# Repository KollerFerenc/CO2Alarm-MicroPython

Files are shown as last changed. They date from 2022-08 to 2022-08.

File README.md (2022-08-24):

# Carbon dioxide (CO<sub>2</sub>) alarm

## Table of Contents

- [Carbon dioxide (CO<sub>2</sub>) alarm](#carbon-dioxide-cosub2sub-alarm)
  - [Table of Contents](#table-of-contents)
  - [Hardware Requirements](#hardware-requirements)
  - [Assembly and wiring](#assembly-and-wiring)
    - [LiPo SHIM for Pico](#lipo-shim-for-pico)
    - [Buzzer](#buzzer)
    - [SCD41 CO2 Sensor](#scd41-co2-sensor)
    - [Diagram](#diagram)
  - [Software and installation](#software-and-installation)
    - [Prerequisites](#prerequisites)
    - [Instalation](#instalation)

## Hardware Requirements

- 1x [Raspberry Pi Pico](https://www.raspberrypi.com/products/raspberry-pi-pico/)
- 1x [SCD41 CO2 Sensor by Pimoroni](https://shop.pimoroni.com/products/scd41-co2-sensor-breakout?variant=39652270833747)
- 1x [Buzzer 5V by Adafruit](https://www.adafruit.com/product/1536)
  - NOTE: can be substituted with regular [piezo buzzer](https://www.adafruit.com/product/160)
  - OBSERVATION: this seemed louder than a regular piezo while playing around with them
- (Optional) 1x [LiPo SHIM for Pico by Pimoroni](https://shop.pimoroni.com/products/pico-lipo-shim?variant=32369543086163)
  - For wired operation this is not required
  - NOTICE: installing headers onto the Pico is recommended
  - NOTE: Pimoroni sells these built into their own Pico models with [4MB](https://shop.pimoroni.com/products/pimoroni-pico-lipo?variant=39386149093459) and [16MB](https://shop.pimoroni.com/products/pimoroni-pico-lipo?variant=39335427080275) of flash memory.
- (Optional) 1x 3.7V rechargeable battery
  - [6700mAh lithium ion battery](https://shop.pimoroni.com/products/high-capacity-lithium-ion-battery-pack?variant=32012684591187)
- Solder, soldering iron and wires to conenct everything together
- (Optional) Breadboard for testing
- (Optional) Headers for the Pico and the CO2 sensor make testing easy

## Assembly and wiring

- [Raspberry Pi Pico documentation and pinout](https://www.raspberrypi.com/documentation/microcontrollers/raspberry-pi-pico.html)
- [SCD41 CO2 Sensor by Pimoroni schematic](https://cdn.shopify.com/s/files/1/0174/1800/files/scd41_breakout_schematic.pdf)
- [LiPo SHIM for Pico schematic](https://cdn.shopify.com/s/files/1/0174/1800/files/lipo_shim_for_pico_schematic.pdf)

### LiPo SHIM for Pico

> [You'll need to solder the SHIM to the back of your Pico, with the power button at the same end as the USB port. The text on the SHIM and the pin labels on the back of the Pico should be facing each other.](https://shop.pimoroni.com/products/pico-lipo-shim?variant=32369543086163)

### Buzzer

- Positive pin -> GPIO 15 (pin 20)
- Negative pin -> GND (pin 18)
  - NOTE: any GND pin is okay

### SCD41 CO2 Sensor

- 3-5V -> 3V3 (pin 36)
- SDA -> GPIO 4 (pin 6)
- SCL -> GPIO 5 (pin 7)
- GND -> GND (pin 8)
  - NOTE: any GND pin is okay

### Diagram

<figure>
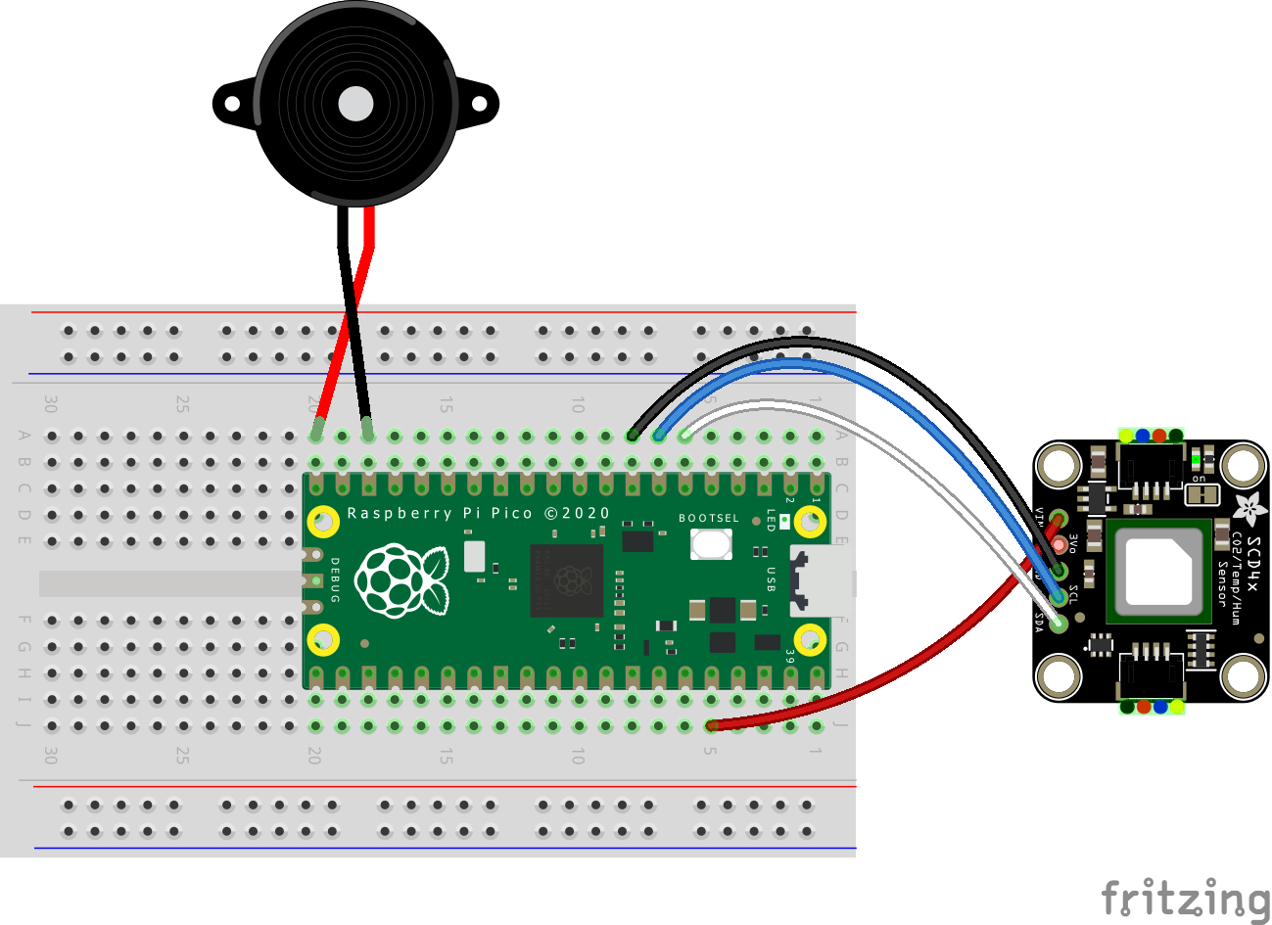
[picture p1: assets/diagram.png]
Wiring diagram.
    
    <figcaption>Wiring diagram.</figcaption>
</figure>

- Sensor shown on the diagram is made by Adafruit and is only a reference. (Couldn't find a model made by Pimoroni.)
  - [Adafruit SCD-41](https://www.adafruit.com/product/5190)

## Software and installation

### Prerequisites

- Install the latest version of [Pimoroni's custom MicroPython](https://github.com/pimoroni/pimoroni-pico) which includes the libraries necessary to use their products. [Follow their installation guide.](https://github.com/pimoroni/pimoroni-pico/blob/main/setting-up-micropython.md)

### Instalation

**1. Clone the repository.**

``` shell
git clone https://github.com/KollerFerenc/CO2Alarm-MicroPython
```

**2. Connect the Raspberry Pi Pico to the computer.**

**3. Launch [Thonny IDE](https://thonny.org/) or the Python IDE of your choice.**

**4. Open the python files in the IDE and save them to the Pico.**
   - src -> main.py
   - src -> buzzers.py

**5. Buzzer selection**

In main.py uncomment which type of buzzer you are using.

*A. Regular piezo buzzer*

```python
# NOTICE: buzzer selection!

# Use this with the 5V Buzzer by Adafruit (https://www.adafruit.com/product/1536)
# BUZZER = Buzzer3v5v(BUZZER_PIN)

# Use this with any regular piezo buzzer
BUZZER = PiezoBuzzer(BUZZER_PIN)
```

*B. [Buzzer 5V by Adafruit](https://www.adafruit.com/product/1536)*

```python
# NOTICE: buzzer selection!

# Use this with the 5V Buzzer by Adafruit (https://www.adafruit.com/product/1536)
BUZZER = Buzzer3v5v(BUZZER_PIN)

# Use this with any regular piezo buzzer
# BUZZER = PiezoBuzzer(BUZZER_PIN)
```

Save the modified file to the Pico.

**6. (Optional) Adjust the values in the Configurables section to match your setup.**

Save the modified file to the Pico.

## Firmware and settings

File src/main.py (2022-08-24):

# CO2 levels - https://www.kane.co.uk/knowledge-centre/what-are-safe-levels-of-co-and-co2-in-rooms
# 250-400 ppm - Normal background concentration in outdoor ambient air
# 400-1000 ppm - Concentrations typical of occupied indoor spaces with good air exchange
# 1000-2000 ppm - Complaints of drowsiness and poor air
# 2000-5000 ppm - Headaches, sleepiness and stagnant, stale, stuffy air.
#                 Poor concentration, loss of attention, increased heart rate and slight nausea may also be present.
# 5000 - Workplace exposure limit (as 8-hour TWA) in most jurisdictions.
# >40000 ppm - Exposure may lead to serious oxygen deprivation resulting in permanent brain damage, coma, even death.

# SCD41 range: 400–5000 ppm

__version__ = "1.3.0"

############################################################
# Imports
############################################################
from re import I
import time
import machine
import os
import micropython
import math

from machine import Pin
from machine import ADC
from machine import PWM
from buzzers import Buzzer3v5v
from buzzers import PiezoBuzzer

import pimoroni_i2c
import breakout_scd41

############################################################
# Configurables
############################################################
SCD41_SDA_PIN = 4  # GPIO pin number on the Pico
SCD41_SCL_PIN = 5  # GPIO pin number on the Pico
BUZZER_PIN = 15  # GPIO pin number on the Pico

# # NOTICE: buzzer selection!

# Use this with the 5V Buzzer by Adafruit (https://www.adafruit.com/product/1536)
# BUZZER = Buzzer3v5v(BUZZER_PIN)

# Use this with any regular piezo buzzer
# BUZZER = PiezoBuzzer(BUZZER_PIN)

# co2 measurement interval in minutes
MEASURE_INTERVAL_MINUTES = 5
# when high co2 is detected, sleep for this fraction of measurement interval
MEASURE_HIGH_NOTICE_SLEEP_FACTOR = 5

# co2 level: normal upper threshold in ppm
CO2_LEVEL_NORMAL_UPPER = 1500
# co2 level: high upper threshold in ppm. Anything higher is considered dangerous!
CO2_LEVEL_HIGH_UPPER = 2500

# battery low warning percent
BATTERY_LOW_WARNING_PERCENT = 15

# print debug message to console
DEBUG = False
# treats first measurement as not trusted, ie sleep after first measurement as if high co2 happened
CHECK_FOR_FIRST_MEASURE = False
ALLOW_LED = False
# Reset Pico after n amount of successful measurements. 0 means no restart.
RESET_AFTER_SUCCESSFUL_MEASUREMENTS = 500

############################################################
# Constants
############################################################
PINS_BREAKOUT_GARDEN = {"sda": SCD41_SDA_PIN, "scl": SCD41_SCL_PIN}
I2C = pimoroni_i2c.PimoroniI2C(**PINS_BREAKOUT_GARDEN)

ONBOARD_LED = Pin(25, Pin.OUT)
VSYS_PIN = ADC(29)
CHARGING_PIN = Pin(24, Pin.IN)

BATTERY_CONVERSION_FACTOR = 3 * 3.3 / 65535
FULL_BATTERY_VOLTAGE = 4.2
EMPTY_BATTERY_VOLTAGE = 2.8

############################################################
# Functions
############################################################
def blink_led(times):
    if not ALLOW_LED:
        return

    turn_off_led()
    for _ in range(times):
        turn_on_led()
        time.sleep(0.1)
        turn_off_led()


def turn_on_led():
    if not ALLOW_LED:
        return

    ONBOARD_LED.value(1)


def turn_off_led():
    ONBOARD_LED.value(0)


def trace(value):
    if DEBUG:
        print("[TRC] {}".format(value))


def debug(value):
    if DEBUG:
        print("[DBG] {}".format(value))


def info(value):
    print("[INF] {}".format(value))


def error(value):
    print("[ERR] {}".format(value))


def battery_status():
    charging = CHARGING_PIN.value() == 1
    voltage = VSYS_PIN.read_u16() * BATTERY_CONVERSION_FACTOR
    percentage = 100 * (
        (voltage - EMPTY_BATTERY_VOLTAGE)
        / (FULL_BATTERY_VOLTAGE - EMPTY_BATTERY_VOLTAGE)
    )
    percentage = max(0.0, min(percentage, 100.0))
    return charging, voltage, percentage


def setup():
    info("Setup start.")
    turn_off_led()
    turn_on_led()
    BUZZER.bequiet()
    time.sleep(1.0)
    info("SCD41 init and start...")
    breakout_scd41.init(I2C)
    time.sleep(1.0)
    breakout_scd41.stop()
    time.sleep(1.0)
    breakout_scd41.start()
    info("SCD41 init and start done.")
    turn_off_led()
    info("Setup finished.")


def loop():
    firstmeasure = CHECK_FOR_FIRST_MEASURE
    measured = False
    stopped = False
    loop_count = 0
    successful_measurement_count = 0
    co2_high_count = 0
    while True:
        debug(
            "Loops: {}, successful measurements: {}".format(
                loop_count, successful_measurement_count
            )
        )

        if (
            RESET_AFTER_SUCCESSFUL_MEASUREMENTS != 0
            and successful_measurement_count >= RESET_AFTER_SUCCESSFUL_MEASUREMENTS
        ):
            info("Restart point reached. Restarting...")
            machine.reset()

        if stopped:
            breakout_scd41.start()

        chrg, v, p = battery_status()
        info("Charging: {}, voltage: {:.2f}V, percentage: {:.0f}%".format(chrg, v, p))

        if not chrg and p <= BATTERY_LOW_WARNING_PERCENT:
            info("Battery level low!")
            BUZZER.beep_boop(2, False)
            time.sleep(2.0)
            BUZZER.beep_boop(2, False)

        debug("Trying to measure...")
        co2_high = False

        if breakout_scd41.ready():
            blink_led(1)
            co2, temperature, humidity = breakout_scd41.measure()
            measured = True
            successful_measurement_count = successful_measurement_count + 1
            info(
                "CO2: {}, Temperature: {:.2f}C, Humidity: {:.0f}%".format(
                    co2, temperature, humidity
                )
            )

            if co2 <= CO2_LEVEL_NORMAL_UPPER:
                info("CO2 level good.")
            elif co2 <= CO2_LEVEL_HIGH_UPPER:
                info("CO2 high.")
                co2_high = True
                co2_high_count = co2_high_count + 1
                BUZZER.beep_boop(5, False)
            else:
                info("CO2 danger.")
                co2_high = True
                co2_high_count = co2_high_count + 1
                BUZZER.beep_boop(30, True)
        else:
            measured = False
            info("SCD41 not ready.")
            blink_led(2)

        if measured:
            measured = False

            debug("CO2 high: {}, High count: {}".format(co2_high, co2_high_count))

            if not co2_high and co2_high_count < 1:
                co2_high_count = 0
                sleep_time = MEASURE_INTERVAL_MINUTES * 60

                if firstmeasure:
                    firstmeasure = False
                    sleep_time = (
                        MEASURE_INTERVAL_MINUTES * 60
                    ) // MEASURE_HIGH_NOTICE_SLEEP_FACTOR
                    info("fm lightsleep start. ({}s)".format(sleep_time))
                    breakout_scd41.stop()
                    stopped = True
                    machine.lightsleep(sleep_time * 1000)
                else:
                    info("deepsleep start. ({}s)".format(sleep_time))
                    breakout_scd41.stop()
                    stopped = True
                    machine.deepsleep(sleep_time * 1000)
            else:
                co2_high_count = co2_high_count - 1
                sleep_time = (
                    MEASURE_INTERVAL_MINUTES * 60
                ) // MEASURE_HIGH_NOTICE_SLEEP_FACTOR
                info("lightsleep start. ({}s)".format(sleep_time))
                breakout_scd41.stop()
                stopped = True
                machine.lightsleep(sleep_time * 1000)

        else:
            time.sleep(1.0)

        loop_count = loop_count + 1


def main():
    setup()
    loop()


############################################################
# Script execution
############################################################

if __name__ == "__main__":
    main()

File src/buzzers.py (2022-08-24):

__version__ = "1.0.0"

############################################################
# Imports
############################################################
import time

from machine import Pin
from machine import PWM

############################################################
# Classes
############################################################


class PiezoBuzzer:
    def __init__(self, id):
        self._buzzer = PWM(Pin(id))
        self._duty_u16 = 5000
        self._tone_gap = 0.3

    @property
    def duty_u16(self):
        return self._duty_u16

    @duty_u16.setter
    def duty_u16(self, value):
        self._duty_u16 = value

    @property
    def tone_gap(self):
        return self._tone_gap

    @tone_gap.setter
    def tone_gap(self, value):
        self._tone_gap = value

    def playtone(self, frequency):
        self._buzzer.duty_u16(self._duty_u16)
        self._buzzer.freq(frequency)

    def bequiet(self):
        self._buzzer.duty_u16(0)

    def beep_boop(self, times, cont, frequency=2000):
        if cont:
            self.playtone(frequency)
            time.sleep(times * self._tone_gap)
            self.bequiet()
        else:
            for _ in range(times):
                self.playtone(frequency)
                time.sleep(self._tone_gap)
                self.bequiet()
                time.sleep(self._tone_gap)
        self.bequiet()


class Buzzer3v5v:
    def __init__(self, id):
        self._buzzer = Pin(id, Pin.OUT)
        self._tone_gap = 0.3

    @property
    def tone_gap(self):
        return self._tone_gap

    @tone_gap.setter
    def tone_gap(self, value):
        self._tone_gap = value

    def bequiet(self):
        self._buzzer.value(0)

    def beep(self):
        self._buzzer.value(1)

    def beep_boop(self, times, cont):
        if cont:
            self.beep()
            time.sleep(times * self._tone_gap)
            self.bequiet()
        else:
            for _ in range(times):
                self.beep()
                time.sleep(self._tone_gap)
                self.bequiet()
                time.sleep(self._tone_gap)
        self.bequiet()


############################################################
# Script execution
############################################################

if __name__ == "__main__":
    pass
